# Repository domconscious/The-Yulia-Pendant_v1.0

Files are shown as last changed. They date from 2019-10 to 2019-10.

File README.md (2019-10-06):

# The Yulia Pendant
Animated pendant using a LOLIN D1 Mini Pro ESP8266 and Adafruit CharliePlex FeatherWing 15x7 LED array

This is a fork of a Clone of Adafruit/FirePendant, modified for the Feather, then modified for ESP8266, I put my thang down, flip it and reverse it, Ti esrever dna ti pilf nwod gnaht ym tup i.  Oh yah, it loops a canned animation sequence on the display.  There's a conversion tool included for grey scale PNGs to a format that draws pixels.

This was originally made for my girlfriend as a courting gift but then it got popular, and well, I made a bunch of these for Burning Man 2019.  These will eventually be produced in mass including battery.  With a 560mah battery you can squeeze 5-7 hours out of it depending on brightness.  I have also included the 3d model for the cases used for Burning Man and the original 3d heart for my girlfirend.

Arduino sketch is comprised of 'Pendant.ino' and 'animation.h' -- latter contains animation frames packed into PROGMEM array holding bounding rectangle + column-major pixel data for each frame.  I have been able to pack over 600kb of frame data composed of over a 1000 frames.

The 'convert_big.py' is a python script that processes all the source PNG images into the required animation.h format. The PNG images were generated from Video to Image Converter by ChitPit.com using stock video found online.  I captured video, processed it using Gif Brewery 3 to an MP4 scaled down to a lower resolution in greyscale, then used Video to Image Converter to PNG files.  The convert_big.py converts those PNGs into the required format for Arduino.  This could probably be simplified and made free with imagemagick if someone wants to contribute.  I made most of this project with the help of French wine.

### Parts list
* LOLIN D1 Mini Pro ESP8266
* 7x15 Adafruit Charliewing led board
* [Tiny momentary close buttons like these](https://www.aliexpress.com/item/32752118872.html)
* [This expensive button](https://eu.mouser.com/ProductDetail/MEC-Switches/5GTH935NCNO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) for sleep function (I'm open to other suggestions!)
* Solid jumper wires
* 560mah lipo battery

### Pinouts
* LOLIN D1 Mini Pro pin4 -> IO, SDA of Charliewing
* LOLIN D1 Mini Pro pin5 -> IO, SCL of Charliewing
* LOLIN D1 Mini Pro pin15 -> Normally Open pin of expensive button above
* LOLIN D1 Mini Pro 3v -> Normally closed pin of expensive button above
* LOLIN D1 Mini Pro Gnd -> Charliewing Gnd
* Charliewing 3v -> Normally closed pin of expensive button above

### Reason for the expensive button
The Charliewing doesn't have a sleep function and will continue to consume power if there _was_ data at any time while powered.  If it's reset and doesn't detect data, it seems to go to sleep and doesn't consume any power.  This button interrupts power to the display (resetting it) while simultaneously brings pin15 HIGH on the ESP8266, putting it to sleep.  This is a hack.

### Todos

 - Configure for multiple animations
 - Enable change animation button
 - Low battery auto sleep (this is a pain in the ass)
 - Enable wifi detection for synchronized animations
 
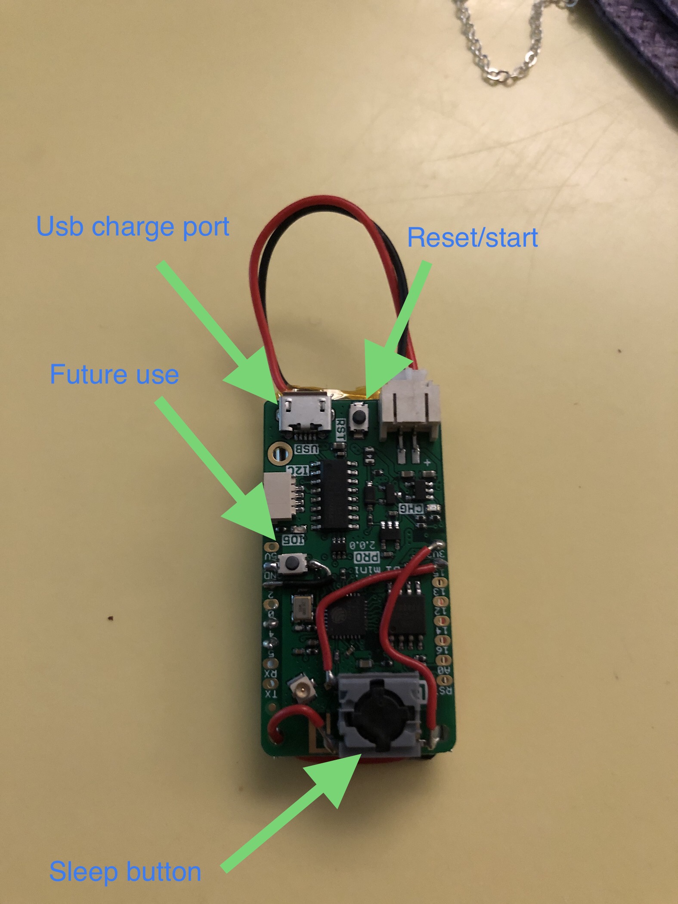
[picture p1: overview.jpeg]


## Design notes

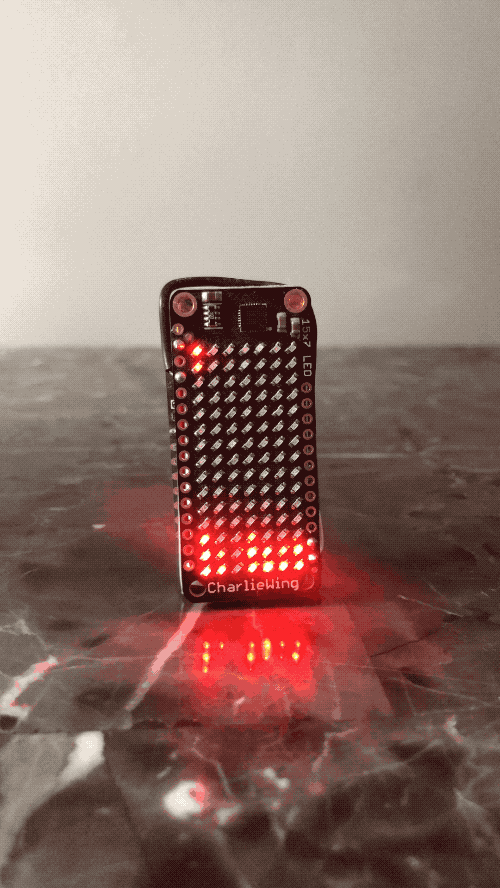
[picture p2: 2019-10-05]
animation.gif

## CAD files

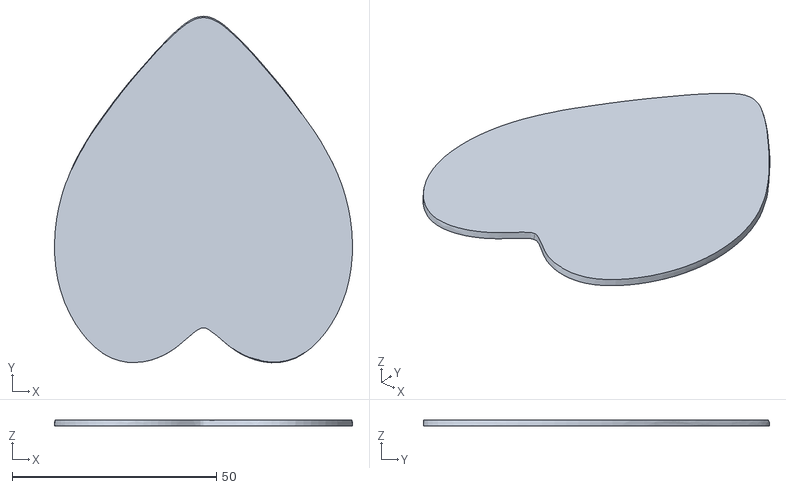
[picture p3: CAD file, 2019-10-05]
3d models/Back of Heart Shaped Box.stl
73.0 x 84.9 x 1.50

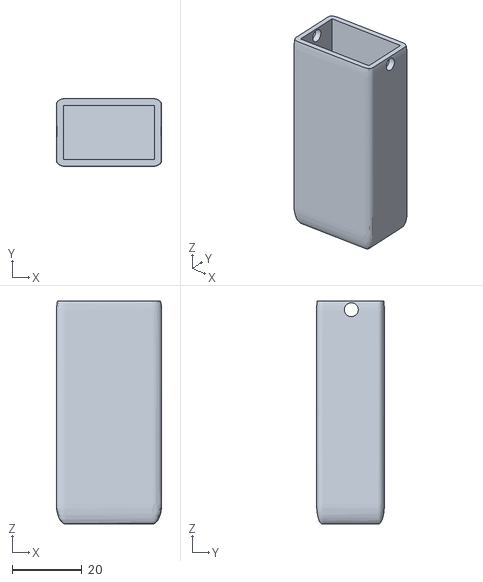
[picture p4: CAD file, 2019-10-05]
3d models/Pendant New.stl
30.2 x 19.5 x 64.0

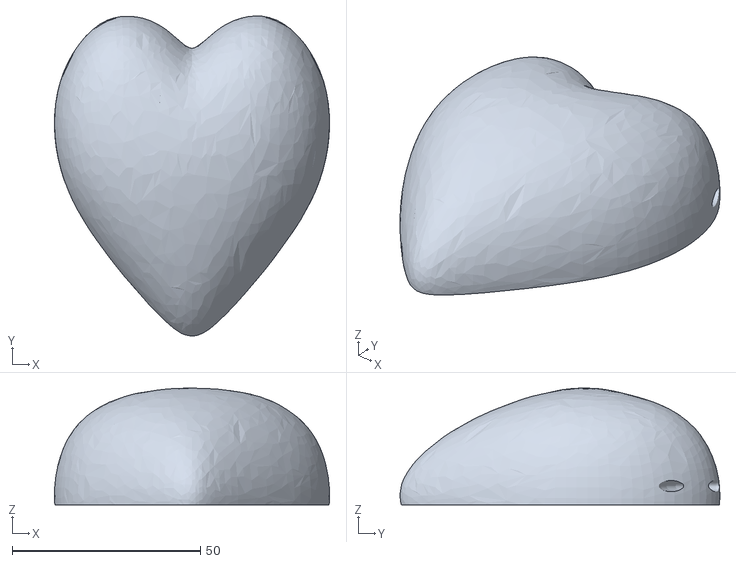
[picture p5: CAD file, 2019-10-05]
3d models/Heart Shaped Box.stl
73.0 x 84.9 x 31.0

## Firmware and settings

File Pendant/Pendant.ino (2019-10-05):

#include <ESP8266WiFi.h>
#include <Adafruit_IS31FL3731.h>
#include "animation.h"       // Flame animation data

// V1.0 Paul Moreno Industrial Lighting
// Based off https://github.com/wbphelps/FeatherCandle
// This is tested working LOLIN D1 Mini Pro w/ an Adafruit 7x15 Featherwing

Adafruit_IS31FL3731_Wing leds = Adafruit_IS31FL3731_Wing();   // using the FeatherWing version

uint8_t        page = 0;    // Front/back buffer control
const uint8_t *ptr  = anim; // Current pointer into animation data
const uint8_t  w    = 7;    // image width
const uint8_t  h    = 15;   // image height
uint8_t        img[w*h];    // Buffer for rendering image
const int  buttonPin = 15;   // the pin that the pushbutton is attached to
int buttonPushCounter = 0;  // counter for the number of button presses
int buttonState = 0;        // current state of the button
int lastButtonState = 0;    // previous state of the button

void setup() {
  Serial.begin(115200);
  Serial.println("Yulia's Pendant");
  Serial.println("The pendant burns for you");
  Serial.print("Push button to sleep");  // This will allow you to charge the battery
  pinMode(buttonPin, INPUT);
  if (! leds.begin()) {
    while (1);
  }
}

void loop() {
  buttonState = digitalRead(buttonPin);
    if (buttonState != lastButtonState) {
    if (buttonState == HIGH) {
      buttonPushCounter++;
      Serial.println("Sleepy time zzz");
      Serial.println(buttonPushCounter);
      delay(90);            // Delay a to avoid bouncing
      leds.clear();
      ESP.deepSleep(0);     // Sleeeeeeeeeep
    } else {
    }
  }
  
  lastButtonState = buttonState;// save the current state as the last state, for next time through the loop
  if (buttonPushCounter % 2 == 0) {
  uint8_t  a, x1, y1, x2, y2, x, y;

  // read NEXT frame.  Start by getting bounding rect for new frame:
  a = pgm_read_byte(ptr++);     // New frame X1/Y1
  if(a >= 0x90) {               // EOD marker? (valid X1 never exceeds 8)
    ptr = anim;                 // Reset animation data pointer to start
    a   = pgm_read_byte(ptr++); // and take first value
  }
  x1 = a >> 4;                  // X1 = high 4 bits
  y1 = a & 0x0F;                // Y1 = low 4 bits
  a  = pgm_read_byte(ptr++);    // New frame X2/Y2
  x2 = a >> 4;                  // X2 = high 4 bits
  y2 = a & 0x0F;                // Y2 = low 4 bits

  // Read rectangle of data from anim[] into portion of img[] buffer
  for(uint8_t y=y1; y<=y2; y++)
    for(uint8_t x=x1; x<=x2; x++) { 
      img[y*w + x] = pgm_read_byte(ptr++);
  }

  page ^= 1;                    // Flip front/back buffer index
  leds.setFrame(page);
  int i = 0;
  for (uint8_t x=0; x<h; x++) {
    for (uint8_t y=0; y<w; y++) {
      leds.drawPixel(x, y, img[i++]);  
      }
    }
  leds.displayFrame(page);
  }
}
